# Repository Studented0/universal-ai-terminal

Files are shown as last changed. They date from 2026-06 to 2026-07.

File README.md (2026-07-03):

# Universal AI Terminal

A pocketable AI terminal that runs Claude Code and Ollama over LTE. Custom carrier board for a Raspberry Pi Compute Module 5, 7" AMOLED touchscreen, and its own cellular modem so it doesn't need WiFi. While a long prompt is running, you can play a game on it instead of staring at the terminal.

---

## Screenshots














(CNC aluminum Enclosure)

Assembly with enclosure  the switches are also going to be 90 degree switches, not vertical ones (not including display)

---

## Why I built this

I kept wanting Claude Code running when I was away from my desk, and there was no good way to do that besides carrying a laptop everywhere. There are videos all over the internet of people sleeping next to a laptop with Claude Code running waking up to accept permissions, or walking around a grocery store with their laptop open, looking crazy. I wanted something pocketable that solves that.

## Hardware

88×155mm, 4-layer board (JLC04161H-3313 stackup), designed in KiCad 9. Six hierarchical schematic sheets: Power, CM5, Display, Cellular, Audio, Controls.

**Compute** — Raspberry Pi Compute Module 5 (8GB RAM, 64GB eMMC, WiFi). Quad-core Cortex-A76 @ 2.4GHz. 

**Display** — DXQ7D0023, 7" AMOLED, 1080×1920, up to 165Hz variable refresh. ICNA3512 driver IC. FT3519T capacitive touch (FocalTech, I2C address 0x38).  Panel connector is a Hirose FH26-39S-0.3SHW (39-pin, 0.3mm pitch); board side is a 40-pin 0.5mm ZIF (Kinghelm KH-FG0.5-H2.0-40PIN), pins 1-39 mapped straight through, pin 40 unused.

**Cellular** — Quectel EC25AFXGA-MINIPCIE, Cat 4 LTE, AT&T/T-Mobile certified for North America. Mini PCIe form factor so it plugs in rather than getting hand-soldered. Uses USB 2.0 internally, not PCIe.

**Power** — BQ25895 handles battery charging and power path from USB-C input. TPS61235P boosts battery voltage up to the 5V the CM5 needs. FUSB302 negotiates USB-PD for faster charging. Two SGM2036 LDOs step down to 3.3V and 1.8V for the display and peripherals.

**I/O** — Two USB-C ports: one power and USB 2.0 (charging), one full data port with USB 3.0 SuperSpeed and a two-transistor load switch for VBUS control. Three tactile buttons (volume up/down, power; though power itself uses the CM5's dedicated PWR_Button pin and needs no GPIO at all). UART debug header, Test Points for power.

**Battery** — 10,000mAh Li-Po.

---

## Enclosure

3mm black-anodized aluminum plate on the back (CNC machined, doubles as a heatsink and structural backing), a thermal pad between the board and plate, then a bottom shell. 

---

## Software

Raspberry Pi OS Lite (64-bit, Bookworm), headless. 
---

## Bill of Materials

Full itemized BOM across all vendors: [`BOM_Universal_AI_Terminal.csv`](BOM_Universal_AI_Terminal.csv)

---

## Repository Structure

```
universal-ai-terminal/
├── HACK CLUB RELATED.kicad_pro    # KiCad project file 
├── HACK CLUB RELATED.kicad_sch    # schematic
├── HACK CLUB RELATED.kicad_pcb    # PCB layout
├── HACK CLUB RELATED.kicad_prl
├── HACK CLUB RELATED.step         # 3D STEP export of the board
├── power.kicad_sch                # Power sheet
├── CM5.kicad_sch                  # CM5 sheet
├── display.kicad_sch              # Display sheet
├── Cellular.kicad_sch             # Cellular sheet
├── audio.kicad_sch                # Audio sheet
├── controls.kicad_sch             # Controls sheet
├── convert_hlabels.py             # script used to convert hierarchical labels to global 
├── libs/easyeda/                  # imported EasyEDA symbols and footprints
├── production/                    # gerbers, BOM, CPL; JLCPCB Fabrication Toolkit output
├── HACK CLUB RELATED.SLDASM       # SolidWorks enclosure assembly
├── Part8.SLDPRT                   # SolidWorks enclosure part
├── BOM_Universal_AI_Terminal.csv  # full itemized BOM
├── journal.md                     # build log
├── LICENSE
└── README.md
```

`.kicad_sch.bak` files and KiCad's auto-generated `-backups/` folders are local working files, not meant to be tracked — they'll stay out of future commits once `.gitignore` is fixed.

---

## License

[MIT](LICENSE)

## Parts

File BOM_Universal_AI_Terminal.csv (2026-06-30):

Category | Ref | Description | Part Number | Qty | Unit Price (USD) | Line Total (USD) | Source | Notes
JLCPCB - Assembled | CN1/CN2 | CM5 Board-to-Board Connector 100-pin 0.4mm | C597931 | 2 |  | Included in PCBA | JLCPCB | DF40C-100DS-0.4V(51); Amphenol CM5 combined footprint
JLCPCB - Assembled | U1 | Battery Charger and Power Path IC | C80200 | 1 |  | Included in PCBA | JLCPCB | BQ25895RTWR; QFN-24
JLCPCB - Assembled | U2 | 5V Boost Converter | C544673 | 1 |  | Included in PCBA | JLCPCB | TPS61235PRWLR; VQFN-9; input from battery SYS rail
JLCPCB - Assembled | U3 | USB-PD Controller | C132291 | 1 |  | Included in PCBA | JLCPCB | FUSB302BMPX; WFQFN-14; I2C0 at GPIO2/3
JLCPCB - Assembled | U4 | 3.3V LDO Regulator | C92402 | 1 |  | Included in PCBA | JLCPCB | SGM2036-3.3YN5G/TR; SOT-23-5
JLCPCB - Assembled | U5 | 1.8V LDO Regulator | C700371 | 1 |  | Included in PCBA | JLCPCB | SGM2036-1.8YN5G/TR; SOT-23-5
JLCPCB - Assembled | U6 | I2S Class D Audio Amplifier | C910544 | 1 |  | Included in PCBA | JLCPCB | MAX98357AETE+T; WLCSP-15; mono left channel
JLCPCB - Assembled | USB1 | USB-C 16-pin Charging Port | C2858270 | 1 |  | Included in PCBA | JLCPCB | Power-only port; PD negotiated via FUSB302
JLCPCB - Assembled | USB2 | USB-C 24-pin Data Port | C53121393 | 1 |  | Included in PCBA | JLCPCB | USB 3.0 SuperSpeed + USB 2.0; VBUS via load switch
JLCPCB - Assembled | CARD1 | Mini PCIe Slot 52-pin Right Angle | C266898 | 1 |  | Included in PCBA | JLCPCB | For EC25 LTE modem; USB 2.0 only internally
JLCPCB - Assembled | SIM1 | Nano SIM Card Socket 7-pin | C7529384 | 1 |  | Included in PCBA | JLCPCB | Paired with EC25 modem
JLCPCB - Assembled | RF1/RF2 | U.FL Antenna Connector | C47986640 | 2 |  | Included in PCBA | JLCPCB | LTE main and diversity ports
JLCPCB - Assembled | CN3 | 40-pin 0.5mm ZIF FPC Connector Bottom Contact | C2797220 | 1 |  | Included in PCBA | JLCPCB | Display interface; pin 40 NC
JLCPCB - Assembled | Q1 | N-Channel MOSFET SOT-23 | C8490 | 1 |  | Included in PCBA | JLCPCB | LBSS138LT1G; VBUS load switch stage 1
JLCPCB - Assembled | Q2 | P-Channel MOSFET SOT-23 | C15155 | 1 |  | Included in PCBA | JLCPCB | AO3407A; VBUS load switch stage 2
JLCPCB - Assembled | J_BAT | JST-PH 2-pin SMD Battery Connector | C265003 | 1 |  | Included in PCBA | JLCPCB | B2B-PH-SM4-TBT
JLCPCB - Assembled | LED1-4 | 0603 Red LED | C2286 | 4 |  | Included in PCBA | JLCPCB | Status and power indicators
JLCPCB - Assembled | L1 | 2.2uH 3A Inductor 1210 | TBD | 1 |  | Included in PCBA | JLCPCB | TPS61235P boost inductor; LCSC to confirm in submitted order
JLCPCB - Assembled | L2 | 1uH 5A Inductor 1210 | TBD | 1 |  | Included in PCBA | JLCPCB | BQ25895 charge inductor; LCSC to confirm in submitted order
JLCPCB - Assembled | R*/C* | 0402 Resistors and Capacitors (all values) | Various | ~45 |  | Included in PCBA | JLCPCB | Per KiCad netlist export; auto-matched by JLCPCB BOM tool
JLCPCB - Fabrication |  | PCB Fabrication 5 boards 90x160mm 4-layer | JLC04161H-3313 | 5 |  | 50.90 | JLCPCB
JLCPCB - Assembly |  | Economic PCBA 2 boards top side |  | 2 |  | 109.79 | JLCPCB | Includes solder paste and stencil
JLCPCB - Shipping |  | Shipping |  | 1 | 44.90 | 44.90 | JLCPCB
JLCPCB - Shipping |  | Customs and Tariffs |  | 1 | 43.31 | 43.31 | JLCPCB
JLCPCB - Shipping |  | Discount |  | 1 | -20.00 | -20.00 | JLCPCB
JLCPCB - Shipping |  | Sales Tax |  | 1 | 13.92 | 13.92 | JLCPCB
JLCPCB TOTAL |  |  |  |  |  | 225.86
JLCPCB CNC |  | Aluminum Plate 88x155x3mm Aluminum 6061 Black Anodized |  | 2 | 12.00 | 24.00 | JLCPCB CNC | 4x M2 mounting holes; structural backing and heat spreader for CM5
JLCPCB CNC TOTAL |  |  |  |  |  | 24.00
Mouser |  | Quectel EC25AFXGA-MINIPCIE 4G LTE Modem | 277-C25AFXGAMINIPCIE | 1 | 75.16 | 75.16 | Mouser | Cat 4 LTE + 3G; mini PCIe form factor; USB 2.0 internally
Mouser |  | Shipping (UPS Ground) |  | 1 | 8.49 | 8.49 | Mouser
Mouser |  | Estimated Tariff |  | 1 | 11.27 | 11.27 | Mouser
Mouser TOTAL |  |  |  |  |  | 94.92
Amazon |  | Raspberry Pi Compute Module 5 - CM5108064 8GB/64GB/WiFi |  | 1 | 185.00 | 185.00 | Amazon | Main compute; quad-core ARM Cortex-A76 2.4GHz; BT 5.0
Amazon |  | Li-Po Battery 10000mAh 3.7V PH2.0 with Protection Board |  | 1 | 16.00 | 16.00 | Amazon | Approx 100x60x11mm; approx price
Amazon | MIC1/MIC2 | INMP441 I2S MEMS Microphone Module (5-pack) |  | 1 | 17.00 | 17.00 | Amazon | 2 used in build; 3 spares; hand solder; approx price
Amazon | SW1-3 | Right-Angle Tactile Switch 6x6x5mm (20-pack) |  | 1 | 8.47 | 8.47 | Amazon | Vol Up/Vol Down/Power; hand solder through-hole
Amazon |  | M2 Screw Nut Washer Assortment 645pcs |  | 1 | 6.00 | 6.00 | Amazon | Assembly hardware; approx price
Amazon |  | Silicone Thermal Pads 0.5/1/1.5mm (100pcs) |  | 1 | 7.00 | 7.00 | Amazon | PCB-to-aluminum plate thermal interface; approx price
Amazon | RF3 | WiFi and BT Dual Band U.FL Antenna 2.4+5GHz |  | 2 | 4.50 | 9.00 | Amazon | CM5 WiFi and Bluetooth internal antennas; approx price
Amazon | RF4/RF5 | LTE 4G Omnidirectional U.FL Antenna 15cm |  | 2 | 3.50 | 7.00 | Amazon | EC25 main and diversity antenna ports; approx price
Amazon | J_SPK | 8 Ohm 1W Mini Speaker with JST-PH1.25 (4-pack) |  | 1 | 7.00 | 7.00 | Amazon | Audio output; 3 spares; approx price
Amazon |  | Shipping and Tax |  |  |  | 20.69 | Amazon
Amazon TOTAL |  |  |  |  |  |  |  | Cart subtotal confirmed at $267.31; $288.00 with shipping and tax
Amazon TOTAL |  |  |  |  |  | 288.00
DXQ | J_DISP | 7in 1080x1920 AMOLED Display with Capacitive Touch |  | 1 | 56.00 | 56.00 | DXQ | ICNA3512 driver IC; FT3519T touch controller; 39-pin 0.3mm FPC; 165Hz VRR
DXQ TOTAL |  |  |  |  |  | 56.00
PMD Way |  | FPC Adapter Cable 0.3mm to 0.5mm | SKU 92320164 (39-pin) or 92320165 (40-pin) | 1 | 30.00 | 30.00 | PMD Way | Listed price $19.95; estimate includes shipping headroom; pin count not yet confirmed against connectors (Hirose FH26-39S-0.3SHW panel side, KH-FG0.5-H2.0-40PIN board side) - awaiting support reply
PMD Way TOTAL |  |  |  |  |  | 30.00 |  | Pin count pending vendor confirmation
 | J4 | 2.54mm 3-pin Male Header - UART Debug Port |  | 1 | 5 | 5 | Amazon | ; PinHeader_1x03_P2.54mm; hand solder
 | J1/J2 (PCB side) | 2.54mm 3-pin Female Socket for Mic Modules |  | 2 | 5 | 10 | Amazon | ; INMP441 modules plug into these; hand solder
GRAND TOTAL |  | Universal AI Terminal |  |  |  | 733.78 |  | Cable estimate from PMD Way ($30); pin count TBD pending support reply;

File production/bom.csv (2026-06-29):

Designator | Footprint | Quantity | Value | LCSC Part #
C1, C21, C27, C3, C8 | 0805 | 5 | 10μF
C10, C11, C12, C15, C18, C19, C2, C20, C22, C24, C25, C26, C28, C30, C31, C32, C33, C4, C5 | 0402 | 19 | 100nF
C13, C14, C16, C17, C29, C6, C7 | 0402 | 7 | 1μF
C23 | 0805 | 1 | 47μF
C9 | 0805 | 1 | 22μF
CARD1 | PCIE-SMD_PCIE-52P40H-3.5 | 1 | PCIE-52P40H | C266898
CN3 | FPC-SMD_40P-P0.50_L5.9-W24.4 | 1 | KH-FG0.5-H2.0-40PIN | C2797220
J1 | JST_PH_S2B-PH-K_1x02_P2.00mm_Horizontal | 1 | Battery_JST_PH2
J2 | PinHeader_1x02_P2.54mm_Vertical | 1 | Conn_01x02
J3, J4 | PinSocket_1x03_P2.54mm_Vertical | 2 | Conn_01x03
J5 | PinHeader_1x03_P2.54mm_Vertical | 1 | Conn_01x03
L1 | 1210 | 1 | 2.2μH 4A
L2 | 1210 | 1 | 1μH 5A
LED1, LED2, LED3, LED4 | LED-SMD_L1.6-W0.8-R-RD | 4 | KT-0603R | C2286
MODULE1 | Raspberry-Pi-5-Compute-Module | 1 | ComputeModule5-CM5
Q1 | SOT-23_L2.9-W1.3-P1.90-LS2.4-BR | 1 | LBSS138LT1G | C8490
Q2 | SOT-23-3_L2.9-W1.6-P1.90-LS2.8-BR | 1 | AO3407A | C15155
R1 | 0402 | 1 | 53.6kΩ
R10, R13, R14, R28, R29, R3, R32 | 0402 | 7 | 10kΩ
R11, R16, R25, R4, R5 | 0402 | 5 | 100kΩ
R12 | 0402 | 1 | 47kΩ
R15, R17 | 0402 | 2 | 5.1kΩ
R18, R21, R22, R8, R9 | 0402 | 5 | 10k
R19, R20 | 0402 | 2 | 4.7kΩ
R23 | 0402 | 1 | 22Ω
R26 | 0402 | 1 | 1kΩ
R27 | 0402 | 1 | 470Ω
R30, R31 | 0402 | 2 | 680Ω
R6 | 0402 | 1 | 825kΩ
R7 | 0402 | 1 | 180kΩ
RF1, RF2 | IPEX-SMD_3P-L2.6-W2.6-LS3.0_RF1200001R | 2 | IPEX-1_C47986640 | C47986640
SIM1 | SIM-SMD_NANO-SIM-7P-H1.37 | 1 | NANO SIM 7P H1.37 | C7529384
SW1, SW2, SW3 | SW_PUSH_6mm_H5mm | 3 | SW_Push
TP1, TP2, TP3, TP4, TP5, TP6 | TestPoint_Pad_D1.5mm | 6 | TestPoint
U1 | Texas_RTW_WQFN-24-1EP_4x4mm_P0.5mm_EP2.7x2.7mm_ThermalVias | 1 | BQ25895RTW
U2 | VQFN-9_L2.5-W2.5-P0.50-TL | 1 | TPS61235PRWLR | C544673
U3 | MLP-14_L2.5-W2.5-P0.50-BL-EP | 1 | FUSB302BMPX | C132291
U4 | SOT-23-5_L3.0-W1.7-P0.95-LS2.8-BR | 1 | SGM2036-3.3YN5G/TR | C92402
U5 | SOT-23-5_L2.9-W1.6-P0.95-LS2.8-BR | 1 | SGM2036-1.8YN5G/TR | C700371
U6 | TQFN-16_L3.0-W3.0-P0.50-BL-EP1.5 | 1 | MAX98357AETE+T | C910544
USB1 | USB-C-SMD_TYPE-C16PIN | 1 | TYPE-C 16PIN 3MD | C2858270
USB2 | USB-C-SMD_TYPE-C-24P-QT | 1 | HMT-TYPE-C-24PIN | C53121393

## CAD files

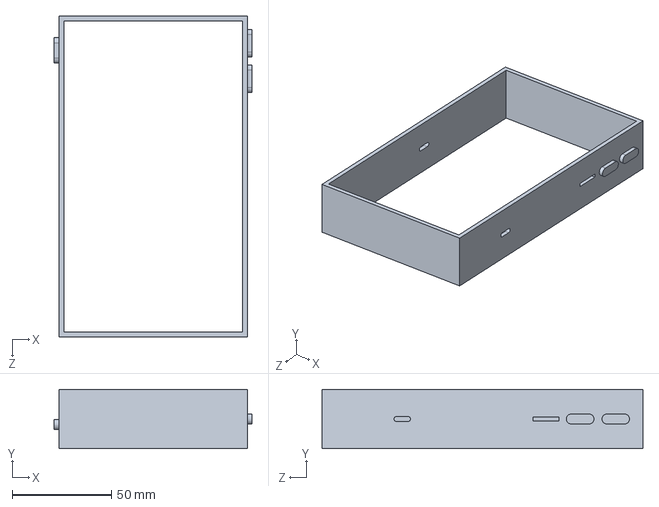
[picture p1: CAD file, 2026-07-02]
CAD/enclosure.SLDPRT
99.9 x 30.0 x 162.0 mm

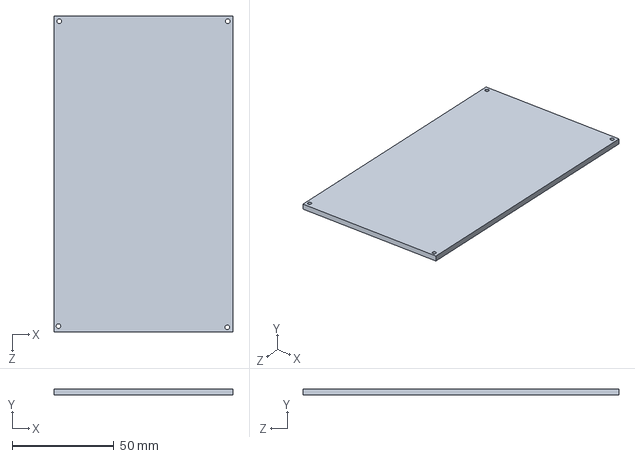
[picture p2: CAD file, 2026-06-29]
CAD/Part3.SLDPRT
87.9 x 3.00 x 154.9 mm

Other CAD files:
CAD/HACK CLUB RELATED.SLDASM

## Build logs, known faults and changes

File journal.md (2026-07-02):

# 6/22/2026 4 PM - all the component searching

_Time spent: 5h_

went through JLCPCB part by part. EC21 variants on JLCPCB are useless for North America, wrong bands and basically no stock. I went to Mouser and found the EC25AFXGA-MINIPCIE which is certified for AT&T and T-Mobile. But its mini PCIe form factor meaning it plugs in instead than being soldered. 

Also Caught a mistake. I had the SGM2036-2.8V LDO in the cart for the display VCI rail, but the datasheet says VCI is 3.3V, not 2.8V. also found the INMP441 mic on JLCPCB is overpriced and out of stock so decided on a 5-pack on Amazon for $11.99. they have through-hole pins, so the module just plugs into a header on the board instead of being SMD soldered.

---

# 6/22/2026 6 PM - display research rabbit hole

_Time spent: 4h_

needed to figure out the display. found the piBrick project, released June 1st, fully open source. it is a handheld CM5 computer using a DXQ AMOLED display connected over MIPI DSI. 

their display is 3.92 inches, which was too small. found the DXQ7D0023 in the catalog, 7 inch, 1080x1920, 165Hz, capacitave touch. listed at $96 publicly. emailed DXQ directly for sample pricing and the datasheet. the 7 inch size is similar to a iPhone 17 Pro Max but narrower than a Switch, fits in pockets, and the screen size makes the terminal actually usable and the demo visible.

During the research I asked gemini about the display driver IC and it confidently told me it was the SH8804B from Sino Wealth with no Linux support and that I would need an HDMI bridge chip. I was starting to plan a whole alternate path around that. DXQ then sent the actual datasheet, and the driver is the ICNA3512, and they gave me an init sequence that lets me write a device tree overlay without recompiling the kernel. Don't trust AI for everything LOL.

---

# 6/22/2026 11 PM - parts locked in, DXQ responded

_Time spent: 2h_

DXQ sent back the full DXQ7D0023 spec sheet and the ICNA3512 driver datasheet. Timing parameters are all in there. 60Hz: HFP=156, HBP=23, VFP=20, VBP=15. Same level of detail for every other refresh rate. 

the FPC connector is still a problem. the display has a 0.3mm pitch 39-pin connector, and JLCPCB does not stock 0.3mm ZIF connectors at all.

---

# 6/23/2026 - DXQ sent the full driver package, display is completely solved

_Time spent: 6h_

Emailed DXQ asking for the init code and driver files. they sent back a full zip with a DSC folder, a non-DSC folder, and a FocalTech touch driver. The main file is a full Qualcomm MDSS panel driver with complete init sequences for all five refresh rates: 60, 90, 120, 144, and 165Hz. the touch driver is complete GPL v2 Linux kernel source for the FT3519T.

Display sample price came back at $59, not the $96 listed publicly. sent DXQ the board side connector info (C2797220, 40 pin 0.5mm ZIF from Kinghelm) and asked if they can make a matching pitch adapter cable. waiting on confirmation before deciding how to handle the 0.3mm to 0.5mm mismatch.
[ICNA3512_Preliminary Datasheet_V0.00.pdf](https://github.com/user-attachments/files/29510919/ICNA3512_Preliminary.Datasheet_V0.00.pdf)
[DXQ7D0023_AMOLED规格书_HDR_10bit.pdf](https://github.com/user-attachments/files/29510915/DXQ7D0023_AMOLED._HDR_10bit.pdf)
[7D0023调试资料.zip](https://github.com/user-attachments/files/29510878/7D0023.zip)

---

# 6/23/2026 - first time opening KiCad for real, power sheet done

_Time spent: 8h_

Started the schematic from scratch in KiCad 9.0.7. Set up a hierarchical structure with six sheets: Power, CM5, Display, Cellular, Audio, Controls.

The power sheet took most of the day. 

Had to search for a while to find the right inductor for the BQ25895. The first JLCPCB results were 0806 package parts rated 1.1 to 2.7A which is not enough headroom for a 3A charger. had to search 1210 package specifically to find anything above 4A saturation current.
I was using hierarchical labels, but little did I know that would come back to stab me. Using a USB 2.0 with PD as the main charging port, with USB 2 data support if needed. Later on added some test points so I can check if any major power problems are happening


---

# 6/26/2026 10 AM - CM5 sheet, pin verification, catching design errors

_Time spent: 5h_

Started on the CM5 sheet and immediately ran into a problem. The pin table from the previous attempt had almost every pin number wrong. I had to pull up the official CM5 datasheet and go through all 200 pins line by line to build a correct table again but correctly this time before touching anything in KiCad.

biggest corrections: the 5V supply inputs are at pins 77, 79, 81, 83, 85, 87 -- not pins 1-4 like the generated data said. pins 1-4 are Ethernet and GND. USB DM and DP were assigned to the wrong connector entirely.

while wiring caught two design errors that would have killed the board. the enable pins on both LDOs were tied to +3V3, which is the LDO output; the LDO can't turn itself on from its own output rail. fixed both enable pins to tie to +5V from the boost converter instead, which comes up first. also found that the CM5 has a dedicated PWR_Button pin (pin 92) that handles power on and off natively with no GPIO needed at all. removed the GPIO power button wiring and just connected pin 92 directly to a button and GND.




---

# 6/26/2026 3 PM - remaining 5 sheets, ERC, 200 errors to clean

_Time spent: 9h_

knocked out Display, Cellular, Audio, and Controls sheets after the CM5 sheet was solid. cellular was the fastest since the EC25 uses USB 2.0 internally and almost all the PCIe pairs on the mini PCIe slot are no-connects.

realized partway through the display sheet that the 16-pin USB-C charging port can't carry USB 3.0 SuperSpeed pairs since those pins don't exist on a 16-pin connector. added a second USB-C port, a 24-pin connector, for mainly data and powered hubs. wired a two-transistor load switch for VBUS control on that port.

ran ERC after all six sheets and got around 200 errors. almost all of them were hierarchical label mismatches between sheets (came back to bite me) I had used hierarchical labels in most places, but they need matching port symbols on the parent sheet to connect properly. The fix I did converting everything to global labels, which just connect by name across all sheets automatically. wrote a simple Python script to do the find-and-replace directly in the .kicad_sch files since doing 40+ labels by hand would have taken wayyy too much time. ERC went from 200 errors to clean after running it again.





---

# 6/27/2026 9 AM - PCB setup and component placement

_Time spent: 5h_

Started PCB layout. board outline is going to be 88 by 155mm. stackup is JLC04161H-3313 (F.Cu for Signal, In1.Cu for power, In2.Cu also for power, and B.cu for backup signal) , 4-layer: F.Cu for signals, In1.Cu solid GND plane, In2.Cu power planes, B.Cu for overflow signals with a GND pour. set up design rules and net classes -- MIPI DSI differential pairs get 0.1mm trace and 0.1mm gap for 90 ohm impedance on the outer layer.

Placement strategy was fixed connectors first since those can't move. Display FPC ZIF at the top center (changed later), two USB-C ports at the bottom(also changed to match a Nintendo Switch more), mini PCIe slot and SIM socket on the right edge, tactile buttons also on the right edge so they'll be accessible when the board is inside the enclosure. CM5 connectors go upper center(changed to bottom center) since the module covers most of the top half of the board. Power ICs clustered near the charging port. LDOs placed between the CM5 connectors and the FPC connector since they power the display directly, and to keep those traces short .

Took a few placement iterations to get everything to fit without components overlapping keepout areas around the connectors.


---

# 6/27/2026 2 PM - MIPI DSI routing, lane polarity inversion

_Time spent: 7h_

MIPI DSI routing was the hardest part of the whole layout. The CM5 J2 connector and the display FPC connector are on opposite sides of the board but not directly across from each other the FPC is top center, and J2 is offset. Getting all five differential pairs (CLK + 4 data lanes) routed cleanly on F.Cu without crossing vias into the GND plane was not possible with this placement (it will be fine for a first version though and I was on a time crunch).

Ended up routing some pairs through B.Cu. Normally you avoid vias on high-speed differential pairs, but the BCM2712 datasheet says it supports lane polarity inversion in device tree, which means if a pair ends up physically swapped at the CM5 connector you can just flip the bit in software and it works fine. the D2 pair ended up inverted at the CM5 side. will add `lane-polarities = <0 0 0 1 0>` to the device tree overlay to correct it. USB 3.0 RX pair also ended up inverted at the CM5 side from the same routing constraint, needs a matching DTS fix.

Measured all five DSI pairs after routing -- all within 5mm of each other in total length. MIPI DSI spec allows up to about 10mm skew at this data rate so no length tuning needed, just verify with a ruler in KiCad. (can definitely work on my PCB tracing LOL)



---

# 6/27/2026 9 PM - finishing routing, BOM tool issues, order prep

_Time spent: 4h_

finished routing all non-critical traces and poured GND. ran DRC and it came back clean other than a few silkscreen overlap warnings that don't affect assembly.

went through the JLCPCB BOM tool to match components. found a couple of issues: it matched a pull-up resistor to a through-hole 1/4W package instead of 0402, which would have been left unassembled without catching it. the inductors L1 and L2 had no automatic match and needed manual LCSC number entry. (I realized I could just use the production files instead of going over it like this)

the CM5 combined footprint also shows as a single component in the BOM tool, but it physically represents two DF40 connectors that have to land at a very specific 5mm center-to-center spacing to match the CM5 module. left a note in the JLCPCB order comments for the engineer explaining this so they don't try to substitute with separately placed connectors. 

---

# 6/28/2026 - DXQ cable drama, aluminum plate, and wrapping up

_Time spent: 4h_

The FPC cable is the last unresolved problem. The display has a 0.3mm pitch 39 pin connector, and the carrier board has a 0.5mm pitch 40 pin ZIF. Those do not connect directly. DXQ quoted custom cables but also mentioned a $0.79 adapter from Taobao. The problem is that the adapter is only 31 pins, and the display needs all 39. pins 32 through 38 are the touch controller I2C, reset, and interrupt lines. a 31-pin cable leaves the touch completely disconnected. Sent a follow-up asking how that would work. display itself is $56 regardless of how the cable gets resolved.

figured out the physical stack. aluminum plate on the bottom, thermal pad on top of that, PCB, battery, display. the thermal pad covers the full back face of the board so the aluminum cannot short anything even if it contacts a pad (the aluminum is also anodized to prevent that). CM5 heat goes through thermal vias to the pad to the plate. anodized black finish adds another layer of insulation.




---

# 6/29/2026 - exact cost quotes locked in, BOM finalized

_Time spent: 5h_

Got exact pricing for everything instead of rough estimates. JLCPCB cart comes to $225.86, CNC plate $24, EC25 from Mouser $94.92, Amazon cart $288, display $56. cable is not finalized, but $10 is a safe bet. Grand total estimate is $700.28. 

built a full itemized BOM CSV

got the GitHub repo set up and pushed. 

# 6/30/2026 - Figured out display connector

_Time spent: 2h_

Did some more research on the display connector and found a 39-pin 0.3 mm to 0.5mm pitch connector! Literally perfect and exactly what I needed. I don't need to use any weird adapters or pay for DXQ to make custom cables! I reached out to the manufacturer to ask for a longer cable and if they could review the datasheets and make sure that it would be compatible too. Everything is now figured out and I am ready to assemble as soon as the parts arrive! 


Some BOM stuff:




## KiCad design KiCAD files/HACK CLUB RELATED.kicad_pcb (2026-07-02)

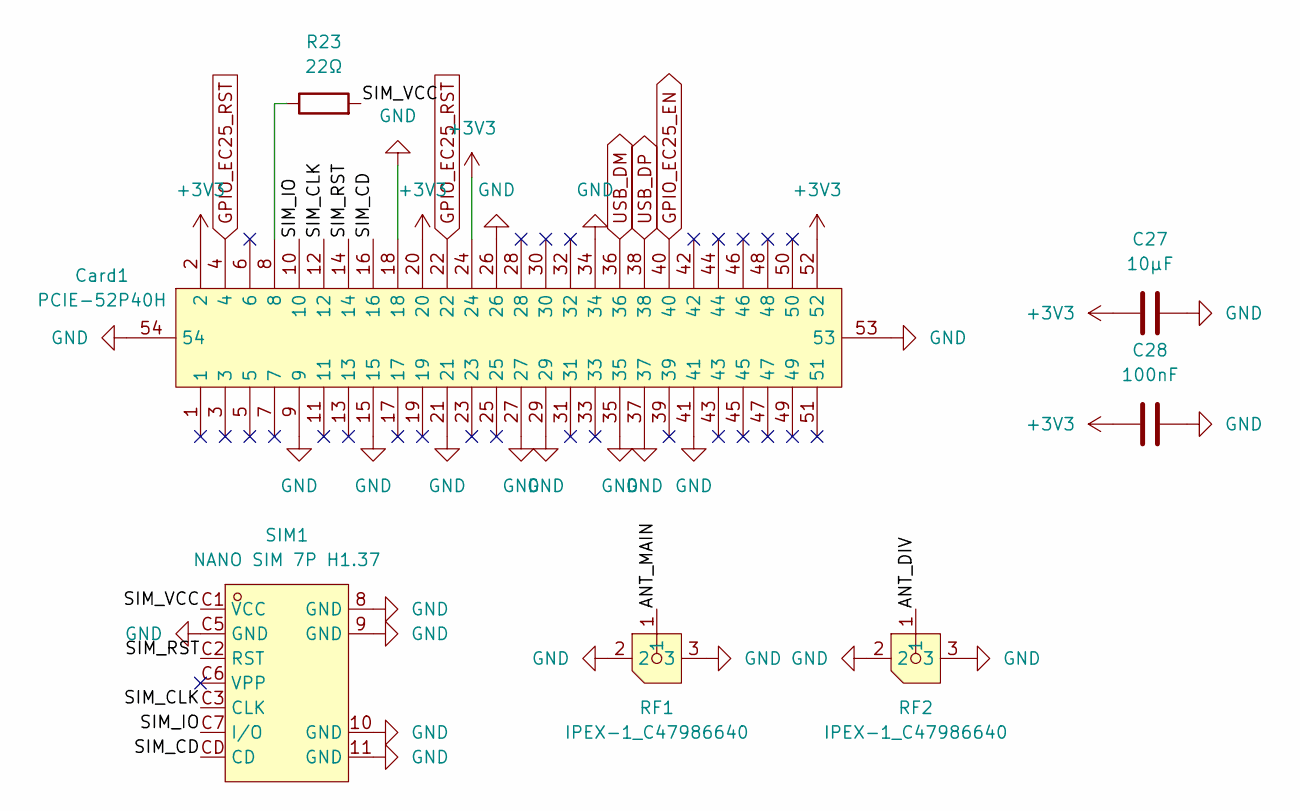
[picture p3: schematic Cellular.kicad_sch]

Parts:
C27: 10μF; C_0805_2012Metric
C28: 100nF; C_0402_1005Metric
Card1: PCIE-52P40H; PCIE-SMD_PCIE-52P40H-3.5; MPN PCIE-52P40H; LCSC Part C266898
R23: 22Ω; R_0402_1005Metric
RF1, RF2: IPEX-1_C47986640; IPEX-SMD_3P-L2.6-W2.6-LS3.0_RF1200001R; MPN IPEX-1; LCSC Part C47986640
SIM1: NANO SIM 7P H1.37; SIM-SMD_NANO-SIM-7P-H1.37; MPN NANO SIM 7P H1.37; LCSC Part C7529384

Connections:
+3V3: C27.1, C28.1, Card1.2, Card1.20, Card1.24, Card1.52; also elsewhere on the board
/Cellular/ANT_DIV: RF2.1
/Cellular/ANT_MAIN: RF1.1
/Cellular/SIM_CD: Card1.16, SIM1.CD
/Cellular/SIM_CLK: Card1.12, SIM1.C3 (CLK)
/Cellular/SIM_IO: Card1.10, SIM1.C7 (I/O)
/Cellular/SIM_RST: Card1.14, SIM1.C2 (RST)
/Cellular/SIM_VCC: R23.2, SIM1.C1 (VCC)
GND: C27.2, C28.2, Card1.9, Card1.15, Card1.18, Card1.21, Card1.26, Card1.27, Card1.29, Card1.34, Card1.35, Card1.37, Card1.41, Card1.53, Card1.54, RF1.2, RF1.3, RF2.2, RF2.3, SIM1.8 (GND), SIM1.9 (GND), SIM1.10 (GND), SIM1.11 (GND), SIM1.C5 (GND); also elsewhere on the board
GPIO_EC25_EN: Card1.40; also elsewhere on the board
GPIO_EC25_RST: Card1.4, Card1.22; also elsewhere on the board
unnamed: Card1.8, R23.1
USB_DP: Card1.38; also elsewhere on the board

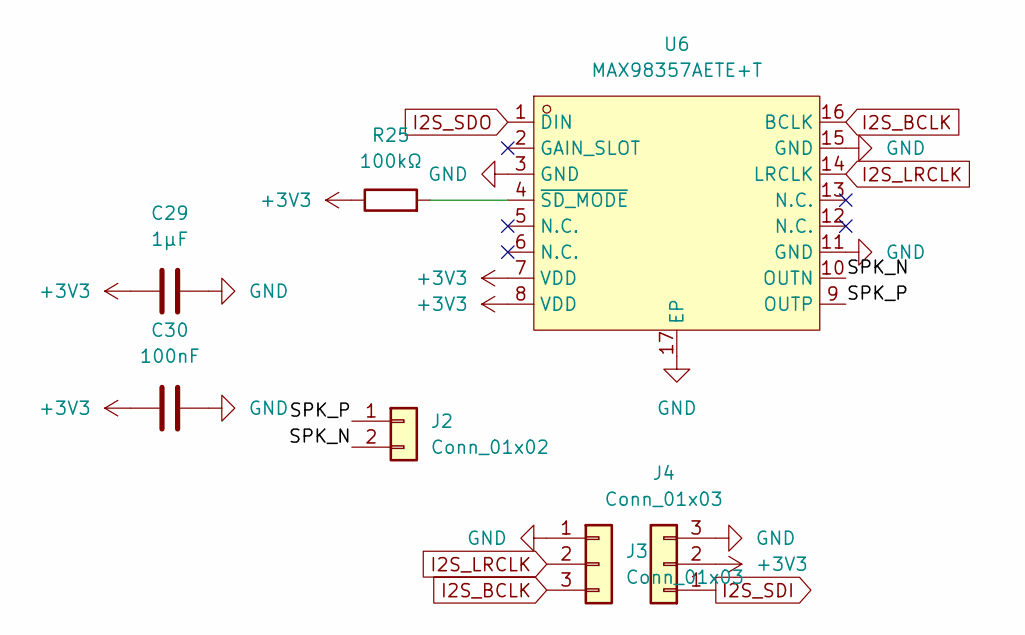
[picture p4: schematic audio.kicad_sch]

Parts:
C29: 1μF; C_0402_1005Metric
C30: 100nF; C_0402_1005Metric
J2: Conn_01x02; PinHeader_1x02_P2.54mm_Vertical
J3, J4: Conn_01x03; PinSocket_1x03_P2.54mm_Vertical
R25: 100kΩ; C_0402_1005Metric
U6: MAX98357AETE+T; TQFN-16_L3.0-W3.0-P0.50-BL-EP1.5; MPN MAX98357AETE+T; LCSC Part C910544

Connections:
+3V3: C29.1, C30.1, J4.2, R25.1, U6.7 (VDD), U6.8 (VDD); also elsewhere on the board
/Audio/SPK_N: J2.2, U6.10 (OUTN)
/Audio/SPK_P: J2.1, U6.9 (OUTP)
GND: C29.2, C30.2, J3.1, J4.3, U6.3 (GND), U6.11 (GND), U6.15 (GND), U6.17 (EP); also elsewhere on the board
I2S_BCLK: J3.3, U6.16 (BCLK); also elsewhere on the board
I2S_LRCLK: J3.2, U6.14 (LRCLK)
I2S_SDI: J4.1; also elsewhere on the board
I2S_SDO: U6.1 (DIN); also elsewhere on the board
unnamed: R25.2, U6.4 (~SD_MODE)

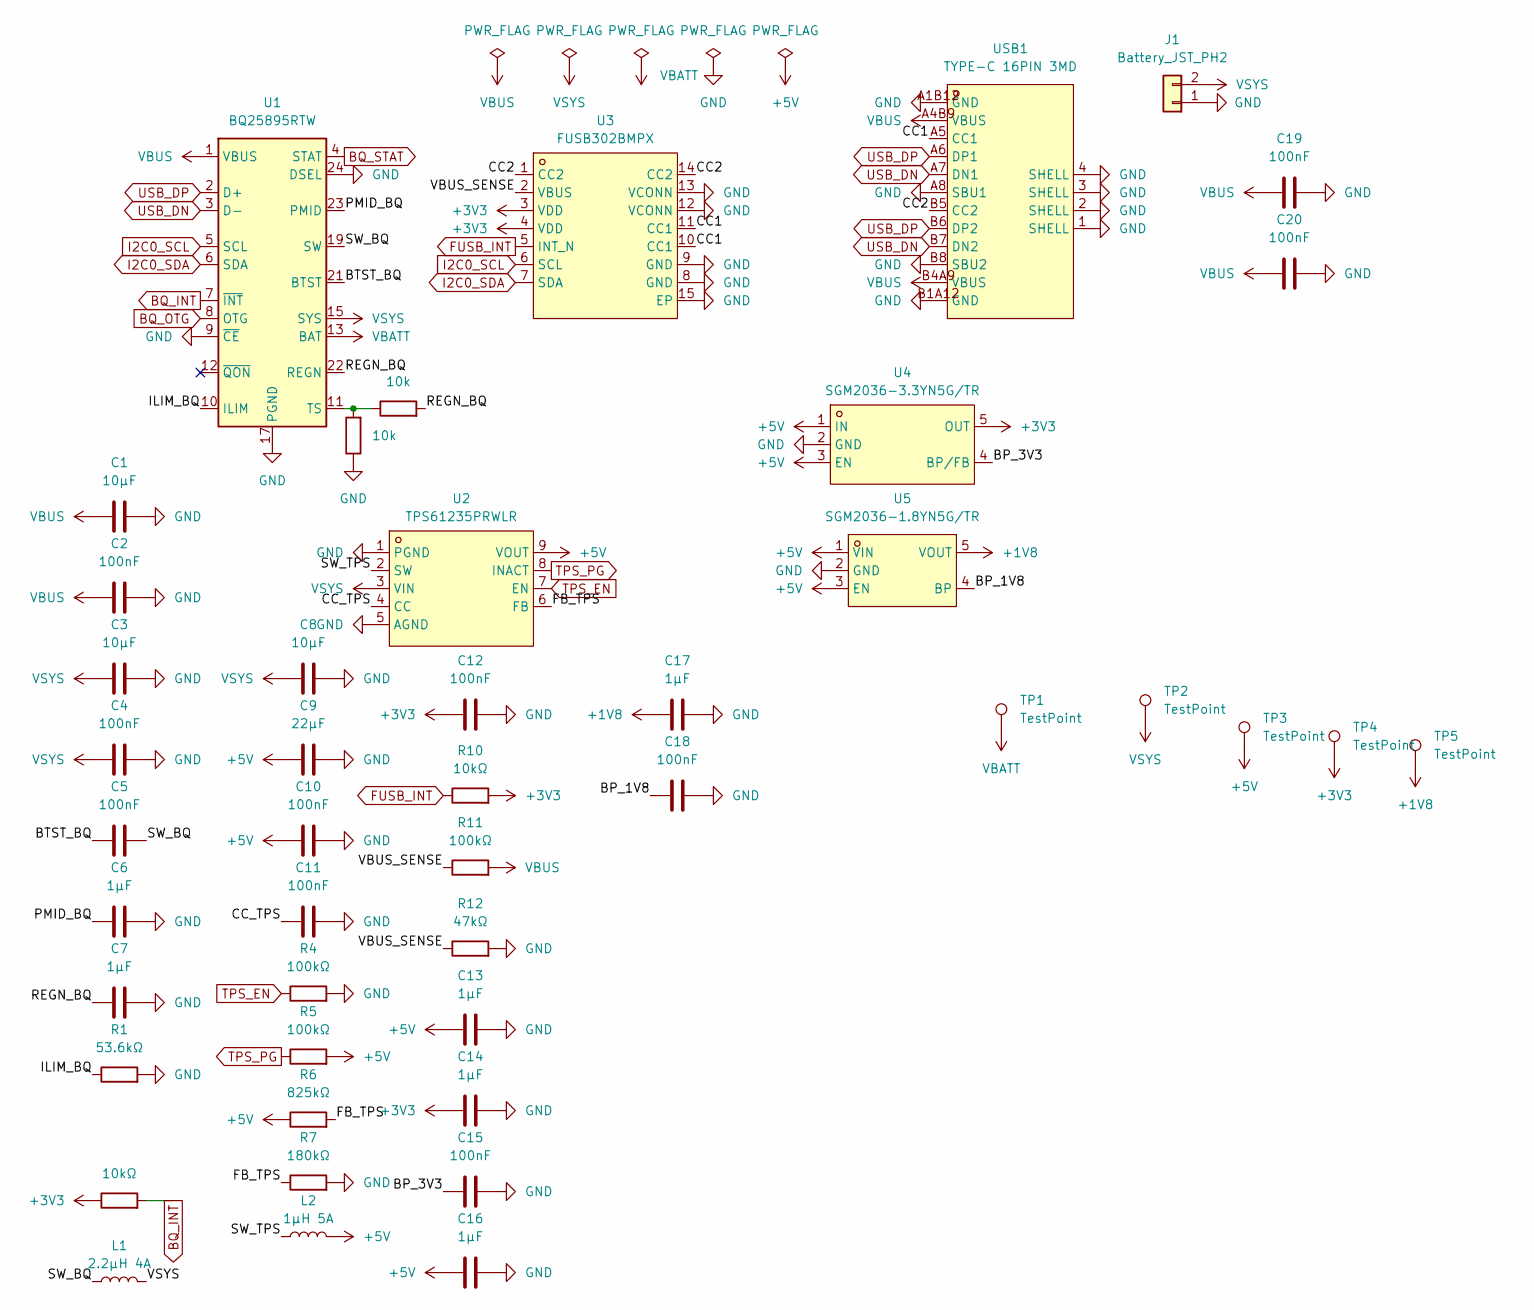
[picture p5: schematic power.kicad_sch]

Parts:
C1, C3, C8: 10μF; C_0805_2012Metric
C2, C4, C5, C10, C11, C12, C15, C18, C19, C20: 100nF; C_0402_1005Metric
C6, C7, C13, C14, C16, C17: 1μF; C_0402_1005Metric
C9: 22μF; C_0805_2012Metric
J1: Battery_JST_PH2; JST_PH_S2B-PH-K_1x02_P2.00mm_Horizontal
L1: 2.2μH 4A; L_1210_3225Metric
L2: 1μH 5A; L_1210_3225Metric
R1: 53.6kΩ; R_0402_1005Metric
R3, R10: 10kΩ; R_0402_1005Metric
R4, R5, R11: 100kΩ; R_0402_1005Metric
R6: 825kΩ; R_0402_1005Metric
R7: 180kΩ; R_0402_1005Metric
R8, R9: 10k; R_0402_1005Metric
R12: 47kΩ; R_0402_1005Metric
TP1, TP2, TP3, TP4, TP5: TestPoint; TestPoint_Pad_D1.5mm
U1: BQ25895RTW; Texas_RTW_WQFN-24-1EP_4x4mm_P0.5mm_EP2.7x2.7mm_ThermalVias
U2: TPS61235PRWLR; VQFN-9_L2.5-W2.5-P0.50-TL; MPN TPS61235PRWLR; LCSC Part C544673
U3: FUSB302BMPX; MLP-14_L2.5-W2.5-P0.50-BL-EP; MPN FUSB302BMPX; LCSC Part C132291
U4: SGM2036-3.3YN5G/TR; SOT-23-5_L3.0-W1.7-P0.95-LS2.8-BR; MPN SGM2036-3.3YN5G/TR; LCSC Part C92402
U5: SGM2036-1.8YN5G/TR; SOT-23-5_L2.9-W1.6-P0.95-LS2.8-BR; MPN SGM2036-1.8YN5G/TR; LCSC Part C700371
USB1: TYPE-C 16PIN 3MD; USB-C-SMD_TYPE-C16PIN; MPN TYPE-C 16PIN 3MD(385); LCSC Part C2858270

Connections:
+1V8: C17.1, TP5.1, U5.5 (VOUT); also elsewhere on the board
+3V3: C12.1, C14.1, R3.1, R10.2, TP4.1, U3.3 (VDD), U3.4 (VDD), U4.5 (OUT); also elsewhere on the board
+5V: C9.1, C10.1, C13.1, C16.1, L2.2, R5.2, R6.1, TP3.1, U2.9 (VOUT), U4.1 (IN), U4.3 (EN), U5.1 (VIN), U5.3 (EN); also elsewhere on the board
/Power/BP_1V8: C18.1, U5.4 (BP)
/Power/BP_3V3: C15.1, U4.4 (BP/FB)
/Power/BTST_BQ: C5.1, U1.21 (BTST)
/Power/CC1: U3.10 (CC1), U3.11 (CC1), USB1.A5 (CC1)
/Power/CC2: U3.1 (CC2), U3.14 (CC2), USB1.B5 (CC2)
/Power/CC_TPS: C11.1, U2.4 (CC)
/Power/FB_TPS: R6.2, R7.1, U2.6 (FB)
/Power/ILIM_BQ: R1.1, U1.10 (ILIM)
/Power/PMID_BQ: C6.1, U1.23 (PMID)
/Power/REGN_BQ: C7.1, R9.2, U1.22 (REGN)
/Power/SW_BQ: C5.2, L1.1, U1.19 (SW), U1.20 (SW)
/Power/SW_TPS: L2.1, U2.2 (SW)
/Power/VBUS_SENSE: R11.1, R12.1, U3.2 (VBUS)
BQ_INT: R3.2, U1.7 (~INT); also elsewhere on the board
BQ_OTG: U1.8 (OTG); also elsewhere on the board
BQ_STAT: U1.4 (STAT); also elsewhere on the board
FUSB_INT: R10.1, U3.5 (INT_N); also elsewhere on the board
GND: C1.2, C2.2, C3.2, C4.2, C6.2, C7.2, C8.2, C9.2, C10.2, C11.2, C12.2, C13.2, C14.2, C15.2, C16.2, C17.2, C18.2, C19.2, C20.2, J1.1, R1.2, R4.2, R7.2, R8.1, R12.2, U1.9 (~CE), U1.17 (PGND), U1.18 (PGND), U1.24 (DSEL), U1.25 (PGND), U2.1 (PGND), U2.5 (AGND), U3.8 (GND), U3.9 (GND), U3.12 (VCONN), U3.13 (VCONN), U3.15 (EP), U4.2 (GND), U5.2 (GND), USB1.1 (SHELL), USB1.2 (SHELL), USB1.3 (SHELL), USB1.4 (SHELL), USB1.A1B12 (GND), USB1.A8 (SBU1), USB1.B1A12 (GND), USB1.B8 (SBU2); also elsewhere on the board
I2C0_SCL: U1.5 (SCL), U3.6 (SCL); also elsewhere on the board
I2C0_SDA: U1.6 (SDA), U3.7 (SDA); also elsewhere on the board
unnamed: R8.2, R9.1, U1.11 (TS)
TPS_EN: R4.1, U2.7 (EN); also elsewhere on the board
TPS_PG: R5.1, U2.8 (INACT); also elsewhere on the board
USB_DP: U1.2 (D+), USB1.A6 (DP1), USB1.B6 (DP2); also elsewhere on the board
VBATT: TP1.1, U1.13 (BAT), U1.14 (BAT); also elsewhere on the board
VBUS: C1.1, C2.1, C19.1, C20.1, R11.2, U1.1 (VBUS), USB1.A4B9 (VBUS), USB1.B4A9 (VBUS)
VSYS: C3.1, C4.1, C8.1, J1.2, L1.2, TP2.1, U1.15 (SYS), U1.16 (SYS), U2.3 (VIN)

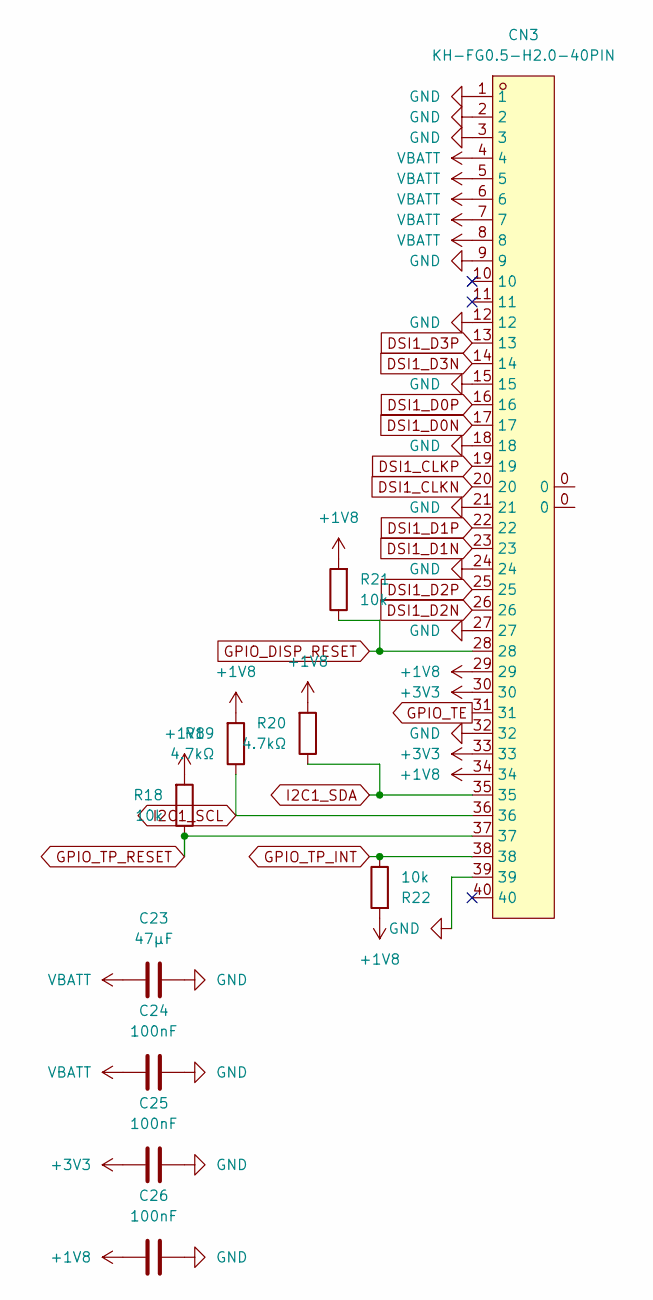
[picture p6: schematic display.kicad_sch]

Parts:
C23: 47μF; C_0805_2012Metric
C24, C25, C26: 100nF; C_0402_1005Metric
CN3: KH-FG0.5-H2.0-40PIN; FPC-SMD_40P-P0.50_L5.9-W24.4; MPN KH-FG0.5-H2.0-40PIN; LCSC Part C2797220
R18, R21, R22: 10k; R_0402_1005Metric
R19, R20: 4.7kΩ; R_0402_1005Metric

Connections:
+1V8: C26.1, CN3.29, CN3.34, R18.2, R19.2, R20.2, R21.2, R22.2; also elsewhere on the board
+3V3: C25.1, CN3.30, CN3.33; also elsewhere on the board
DSI1_CLKN: CN3.20; also elsewhere on the board
DSI1_CLKP: CN3.19; also elsewhere on the board
DSI1_D0N: CN3.17; also elsewhere on the board
DSI1_D0P: CN3.16; also elsewhere on the board
DSI1_D1N: CN3.23; also elsewhere on the board
DSI1_D1P: CN3.22; also elsewhere on the board
DSI1_D2N: CN3.26; also elsewhere on the board
DSI1_D2P: CN3.25; also elsewhere on the board
DSI1_D3N: CN3.14; also elsewhere on the board
DSI1_D3P: CN3.13; also elsewhere on the board
GND: C23.2, C24.2, C25.2, C26.2, CN3.1, CN3.2, CN3.3, CN3.9, CN3.12, CN3.15, CN3.18, CN3.21, CN3.24, CN3.27, CN3.32, CN3.39; also elsewhere on the board
GPIO_DISP_RESET: CN3.28, R21.1; also elsewhere on the board
GPIO_TE: CN3.31; also elsewhere on the board
GPIO_TP_INT: CN3.38, R22.1; also elsewhere on the board
GPIO_TP_RESET: CN3.37, R18.1; also elsewhere on the board
I2C1_SCL: CN3.36, R19.1; also elsewhere on the board
I2C1_SDA: CN3.35, R20.1; also elsewhere on the board
VBATT: C23.1, C24.1, CN3.4, CN3.5, CN3.6, CN3.7, CN3.8; also elsewhere on the board

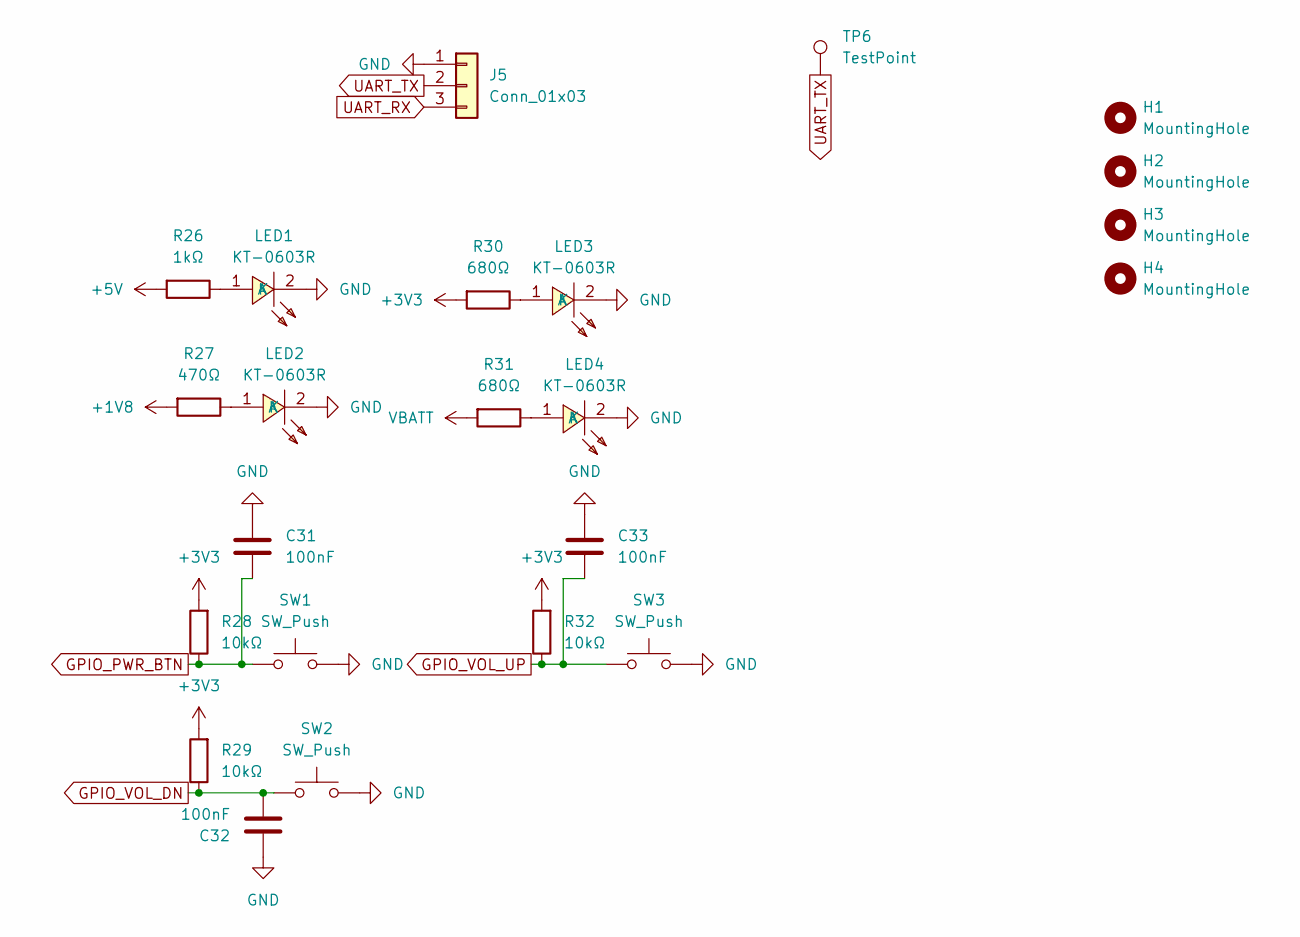
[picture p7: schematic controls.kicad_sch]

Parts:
C31, C32, C33: 100nF; C_0402_1005Metric
H1, H2, H3, H4: MountingHole; MountingHole_2.2mm_M2
J5: Conn_01x03; PinHeader_1x03_P2.54mm_Vertical
LED1, LED2, LED3, LED4: KT-0603R; LED-SMD_L1.6-W0.8-R-RD; MPN KT-0603R; LCSC Part C2286
R26: 1kΩ; R_0402_1005Metric
R27: 470Ω; R_0402_1005Metric
R28, R29, R32: 10kΩ; R_0402_1005Metric
R30, R31: 680Ω; R_0402_1005Metric
SW1, SW2, SW3: SW_Push; SW_PUSH_6mm_H5mm
TP6: TestPoint; TestPoint_Pad_D1.5mm

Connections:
+1V8: R27.2; also elsewhere on the board
+3V3: R28.2, R29.2, R30.2, R32.2; also elsewhere on the board
+5V: R26.2; also elsewhere on the board
GND: C31.1, C32.1, C33.1, J5.1, LED1.2 (K), LED2.2 (K), LED3.2 (K), LED4.2 (K), SW1.2, SW2.2, SW3.2; also elsewhere on the board
GPIO_PWR_BTN: C31.2, R28.1, SW1.1; also elsewhere on the board
GPIO_VOL_DN: C32.2, R29.1, SW2.1; also elsewhere on the board
GPIO_VOL_UP: C33.2, R32.1, SW3.1; also elsewhere on the board
unnamed: LED1.1 (A), R26.1
unnamed: LED2.1 (A), R27.1
unnamed: LED3.1 (A), R30.1
unnamed: LED4.1 (A), R31.1
UART_RX: J5.3; also elsewhere on the board
UART_TX: J5.2, TP6.1; also elsewhere on the board
VBATT: R31.2; also elsewhere on the board

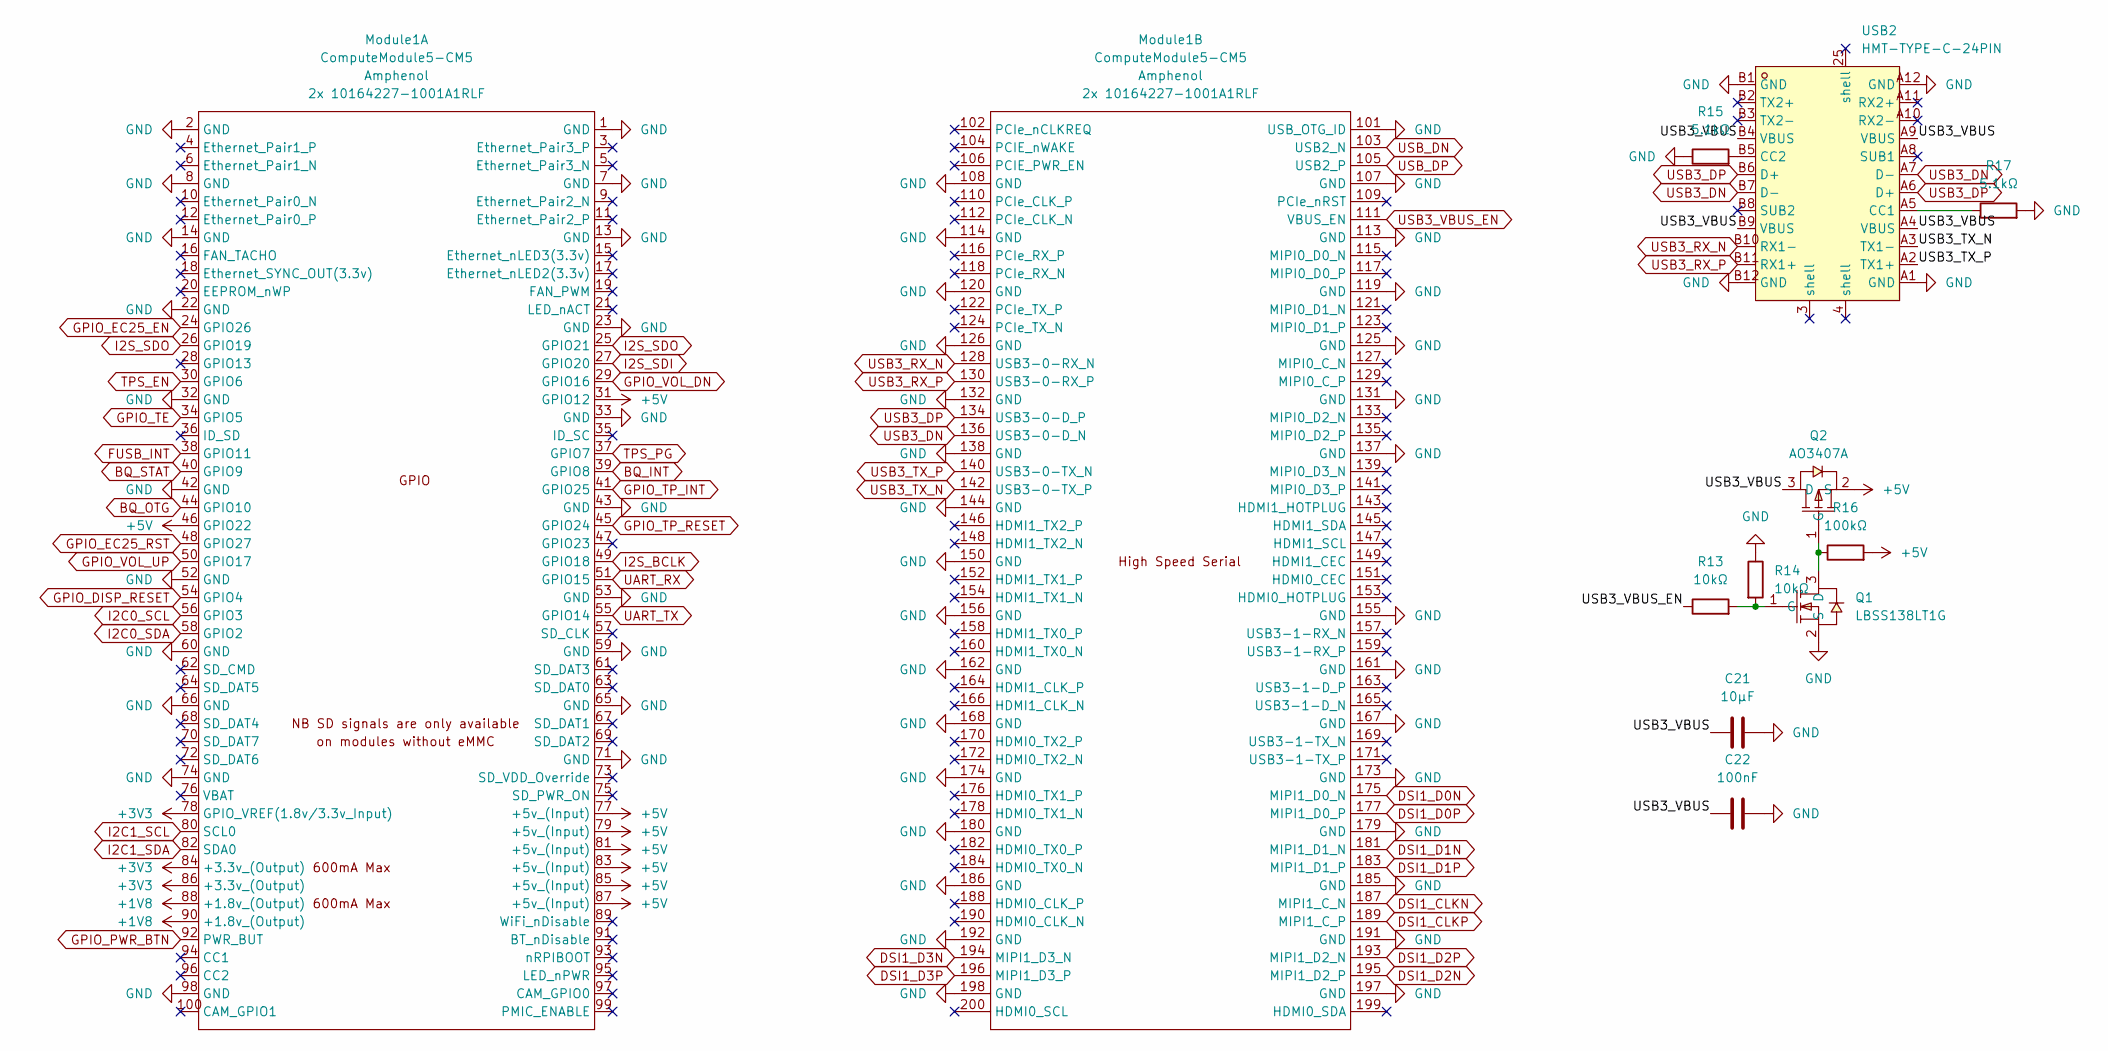
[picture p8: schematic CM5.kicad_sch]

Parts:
C21: 10μF; C_0805_2012Metric
C22: 100nF; C_0402_1005Metric
Module1: ComputeModule5-CM5; Raspberry-Pi-5-Compute-Module
Q1: LBSS138LT1G; SOT-23_L2.9-W1.3-P1.90-LS2.4-BR; MPN LBSS138LT1G; LCSC Part C8490
Q2: AO3407A; SOT-23-3_L2.9-W1.6-P1.90-LS2.8-BR; MPN AO3407A; LCSC Part C15155
R13, R14: 10kΩ; R_0402_1005Metric
R15, R17: 5.1kΩ; R_0402_1005Metric
R16: 100kΩ; R_0402_1005Metric
USB2: HMT-TYPE-C-24PIN; USB-C-SMD_TYPE-C-24P-QT; MPN HMT-TYPE-C-24PIN; LCSC Part C53121393

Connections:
+1V8: Module1.88 (+1.8v_(Output)), Module1.90 (+1.8v_(Output)); also elsewhere on the board
+3V3: Module1.78 (GPIO_VREF(1.8v/3.3v_Input)), Module1.84 (+3.3v_(Output)), Module1.86 (+3.3v_(Output)); also elsewhere on the board
+5V: Module1.31 (GPIO12), Module1.46 (GPIO22), Module1.77 (+5v_(Input)), Module1.79 (+5v_(Input)), Module1.81 (+5v_(Input)), Module1.83 (+5v_(Input)), Module1.85 (+5v_(Input)), Module1.87 (+5v_(Input)), Q2.2 (S), R16.2; also elsewhere on the board
/CM5/USB3_VBUS: C21.1, C22.1, Q2.3 (D), USB2.A4 (VBUS), USB2.A9 (VBUS), USB2.B4 (VBUS), USB2.B9 (VBUS)
BQ_INT: Module1.39 (GPIO8); also elsewhere on the board
BQ_OTG: Module1.44 (GPIO10); also elsewhere on the board
BQ_STAT: Module1.40 (GPIO9); also elsewhere on the board
DSI1_CLKN: Module1.187 (MIPI1_C_N); also elsewhere on the board
DSI1_CLKP: Module1.189 (MIPI1_C_P); also elsewhere on the board
DSI1_D0N: Module1.175 (MIPI1_D0_N); also elsewhere on the board
DSI1_D0P: Module1.177 (MIPI1_D0_P); also elsewhere on the board
DSI1_D1N: Module1.181 (MIPI1_D1_N); also elsewhere on the board
DSI1_D1P: Module1.183 (MIPI1_D1_P); also elsewhere on the board
DSI1_D2N: Module1.195 (MIPI1_D2_P); also elsewhere on the board
DSI1_D2P: Module1.193 (MIPI1_D2_N); also elsewhere on the board
DSI1_D3N: Module1.194 (MIPI1_D3_N); also elsewhere on the board
DSI1_D3P: Module1.196 (MIPI1_D3_P); also elsewhere on the board
FUSB_INT: Module1.38 (GPIO11); also elsewhere on the board
GND: C21.2, C22.2, Module1.1 (GND), Module1.2 (GND), Module1.7 (GND), Module1.8 (GND), Module1.13 (GND), Module1.14 (GND), Module1.22 (GND), Module1.23 (GND), Module1.32 (GND), Module1.33 (GND), Module1.42 (GND), Module1.43 (GND), Module1.52 (GND), Module1.53 (GND), Module1.59 (GND), Module1.60 (GND), Module1.65 (GND), Module1.66 (GND), Module1.71 (GND), Module1.74 (GND), Module1.98 (GND), Module1.101 (USB_OTG_ID), Module1.107 (GND), Module1.108 (GND), Module1.113 (GND), Module1.114 (GND), Module1.119 (GND), Module1.120 (GND), Module1.125 (GND), Module1.126 (GND), Module1.131 (GND), Module1.132 (GND), Module1.137 (GND), Module1.138 (GND), Module1.144 (GND), Module1.150 (GND), Module1.155 (GND), Module1.156 (GND), Module1.161 (GND), Module1.162 (GND), Module1.167 (GND), Module1.168 (GND), Module1.173 (GND), Module1.174 (GND), Module1.179 (GND), Module1.180 (GND), Module1.185 (GND), Module1.186 (GND), Module1.191 (GND), Module1.192 (GND), Module1.197 (GND), Module1.198 (GND), Q1.2 (S), R14.1, R15.1, R17.2, USB2.A1 (GND), USB2.A12 (GND), USB2.B1 (GND), USB2.B12 (GND); also elsewhere on the board
GPIO_DISP_RESET: Module1.54 (GPIO4); also elsewhere on the board
GPIO_EC25_EN: Module1.24 (GPIO26); also elsewhere on the board
GPIO_EC25_RST: Module1.48 (GPIO27); also elsewhere on the board
GPIO_PWR_BTN: Module1.92 (PWR_BUT); also elsewhere on the board
GPIO_TE: Module1.34 (GPIO5); also elsewhere on the board
GPIO_TP_INT: Module1.41 (GPIO25); also elsewhere on the board
GPIO_TP_RESET: Module1.45 (GPIO24); also elsewhere on the board
GPIO_VOL_DN: Module1.29 (GPIO16); also elsewhere on the board
GPIO_VOL_UP: Module1.50 (GPIO17); also elsewhere on the board
I2C0_SCL: Module1.56 (GPIO3); also elsewhere on the board
I2C0_SDA: Module1.58 (GPIO2); also elsewhere on the board
I2C1_SCL: Module1.80 (SCL0); also elsewhere on the board
I2C1_SDA: Module1.82 (SDA0); also elsewhere on the board
I2S_BCLK: Module1.49 (GPIO18); also elsewhere on the board
I2S_SDI: Module1.27 (GPIO20); also elsewhere on the board
I2S_SDO: Module1.25 (GPIO21), Module1.26 (GPIO19); also elsewhere on the board
unnamed: Q1.3 (D), Q2.1 (G), R16.1
unnamed: Q1.1 (G), R13.2, R14.2
unnamed: R17.1, USB2.A5 (CC1)
unnamed: R15.2, USB2.B5 (CC2)
TPS_EN: Module1.30 (GPIO6); also elsewhere on the board
TPS_PG: Module1.37 (GPIO7); also elsewhere on the board
UART_RX: Module1.51 (GPIO15); also elsewhere on the board
UART_TX: Module1.55 (GPIO14); also elsewhere on the board
USB3_DN: Module1.136 (USB3-0-D_N), USB2.A7 (D-), USB2.B7 (D-)
USB3_DP: Module1.134 (USB3-0-D_P), USB2.A6 (D+), USB2.B6 (D+)
USB3_RX_N: Module1.128 (USB3-0-RX_N), USB2.B10 (RX1-)
USB3_RX_P: Module1.130 (USB3-0-RX_P), USB2.B11 (RX1+)
USB3_TX_N: Module1.142 (USB3-0-TX_P), USB2.A3 (TX1-)
USB3_TX_P: Module1.140 (USB3-0-TX_N), USB2.A2 (TX1+)
USB3_VBUS_EN: Module1.111 (VBUS_EN), R13.1
USB_DP: Module1.105 (USB2_P); also elsewhere on the board

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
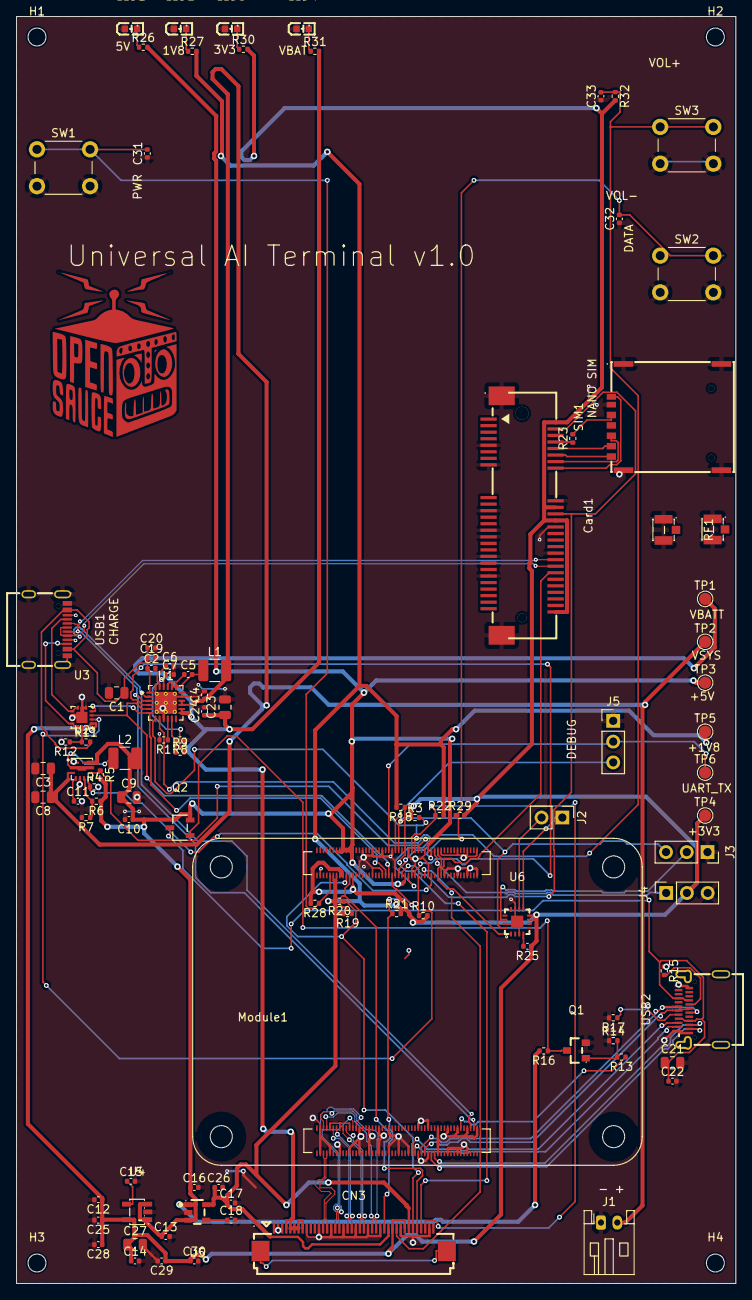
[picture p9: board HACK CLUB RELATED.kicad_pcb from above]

Board: 4 copper layers, 88.0 x 155.0 mm, 103 parts (0 on the bottom side), 83 nets.

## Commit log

2026-06-29 Initial commit: schematics, PCB layout, BOM
    [BOM_Universal_AI_Terminal.csv, CM5.kicad_sch, Cellular.kicad_sch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]
2026-06-30 Revise journal entries for project updates
    Updated journal entries for project progress, including parts selection, display research, schematic design, PCB layout, and cost estimates. Adjusted details for clarity and accuracy.
2026-06-30 Revise PCB layout and document changes
    Updated PCB layout details, including MIPI DSI routing challenges and physical stack configuration. Added images for visual reference.
2026-06-30 Fix gitignore filename
    [HACK CLUB RELATED.kicad_pcb]
2026-06-30 Update BOM with new components and totals
    [BOM_Universal_AI_Terminal.csv]
2026-06-30 Adjust total values and refine PMD Way description
    fixed parsing error
    [BOM_Universal_AI_Terminal.csv]
2026-06-30 Reorganize repository structure
    [CM5.kicad_sch, Cellular.kicad_sch, HACK CLUB RELATED.SLDASM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]
2026-07-02 Add CAD assembly and enclosures
    [HACK CLUB RELATED.kicad_pcb, HACK CLUB RELATED.step, enclosure.SLDPRT]
